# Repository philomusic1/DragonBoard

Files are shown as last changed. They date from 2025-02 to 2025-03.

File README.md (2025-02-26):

This is my keyboard inspired by the Corne Split Keyboard

It is a 58 Key Keyboard, with 2 Rotary encoders which have their switches wired into the Keyboard Switches matrix so it can be used as 60% keyboard
It is designed to be compatible with the Nice!Nano v2 and niceview display (the display can be swapped out for a oled one)
It is a reverisble PCB, so you only needs to send 1 gerber to your PCB manufacturer saving on costs and making it easier
The case is an acrylic case with a display protecter added
It is designed to be a wireless Keyboard with cherry mx hotswap switches with Per key RGB using SK6812 mini-e

Photos of the board follow Below:

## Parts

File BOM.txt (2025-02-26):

Bill of materials

10x 9mm M2 spacers/standoffs https://www.aliexpress.com/item/4000136343429.html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

4x 12mm M2 spacers/standoffs female threaded https://www.aliexpress.com/item/4000136343429.html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

28x 4mm M2 Screws https://mechboards.co.uk/products/m2-screws?variant=40295475740877

2x Wireless Pro Micro MCUs https://www.aliexpress.com/item/1005007738886550.html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

4x 12 4mm spring pin headers and sockets

58x Gateron G Pro 3.0 Silver https://www.mechmods.co.uk/products/gateron-g-pro-3-0-speed-silver-switches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

58x Cherry MX keyboard switch sockets https://mechboards.co.uk/products/kailh-hotswap-sockets

58x keycaps. https://www.aliexpress.com/item/1005008131935903.html?spm=a2g0o.cart.0.0.6f5338daPuBV3f&mp=1#nav-review

58x SK6812 Mini leds https://mechboards.co.uk/products/rgb-smd-leds?variant=40436774011085

58x 100nF Ceramic Capacitors https://www.digikey.co.uk/en/products/detail/samsung-electro-mechanics/CL05B104KP5VPNC/20498482

1x AO3401A Transistor https://www.digikey.co.uk/en/products/detail/alpha-omega-semiconductor-inc/AO3401A/1855773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

1x 2N7002 Transistor https://www.digikey.co.uk/en/products/detail/onsemi/2N7002/244345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

2x 0402 10k resistors https://www.digikey.co.uk/en/products/detail/samsung-electro-mechanics/RC1005F103CS/3903439

1x 0402 100 resistor https://www.digikey.co.uk/en/products/detail/yageo/RC0402JR-07100RL/726415

60x diodes 1N4148W SOD123 package https://www.digikey.co.uk/en/products/detail/diodes-incorporated/1N4148W-13-F/1933928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

2 buttons Momentary, tactile, through-hole, 2 pins: 3x6x4.3mm. https://www.digikey.co.uk/en/products/detail/c-k/PTS636-SM25F-SMTR-LFS/10071742

2 SPDT SMT slide switches https://www.digikey.co.uk/en/products/detail/nidec-copal-electronics/CUS-12TB/1124222

2 JST headers https://www.digikey.co.uk/en/products/detail/jst-sales-america-inc/S2B-PH-K-S/926626

4x LiPo Batteries 306080 https://www.aliexpress.com/item/1005006257821127.html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

2x OLED Displays https://www.aliexpress.com/item/1005007069127189.html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

2x ec11 encoder https://mechboards.co.uk/products/rotary-encoder

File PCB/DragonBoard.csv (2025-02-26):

Id | Designator | Footprint | Quantity | Designation | Supplier and ref
1 | SW_BATT+1,SW_BATT+2 | SW_SPDT_PCM12 | 2 | SW_SPST
2 | SW31 | RotaryEncoder_Alps_EC11E-Switch_Vertical_H20mm-keebio_modified | 1 | Rotary_Encoder_Switch
3 | TH7,TH4,TH6,TH3,TH5 | HOLE_M2_TH | 5 | HOLE
4 | U1 | ProMicro | 1 | ProMicro
5 | JP1,JP2,JP3,JP4,JP0,JP7,JP8,JP9,JP6,JP5 | Jumper_small | 10 | Jumper_NO_Small
6 | RSW1 | TACT_SWITCH_TVBP06 | 1 | SW_RST
7 | D1,D2,D3,D4,D5,D6,D13,D19,D25,D26,D7,D8,D9,D10,D11,D12,D27,D15,D16,D17,D18,D28,D29,D24,D20,D21,D22,D23,D14,D30 | crkbd-diode | 30 | D
8 | SW1,SW3,SW13,SW14,SW19,SW21,SW23,SW26,SW27,SW12,SW18,SW24,SW4,SW5,SW8,SW10,SW9,SW16,SW6,SW7,SW30,SW11,SW22,SW17,SW29,SW15,SW2,SW20,SW28 | SK6812MINI_and_cherry | 29 | SW_PUSH_LED
9 | TH1,TH2 | M2_HOLE_PCB | 2 | HOLE
10 | J3 | OLED_NICEVIEW_COMBO_HDR_5Pin | 1 | OLED
11 | JST_BATT2,JST_BATT1 | JST_PH_S2B-PH-K_1x02_P2.00mm_DoubleSided | 2 | Conn_01x02

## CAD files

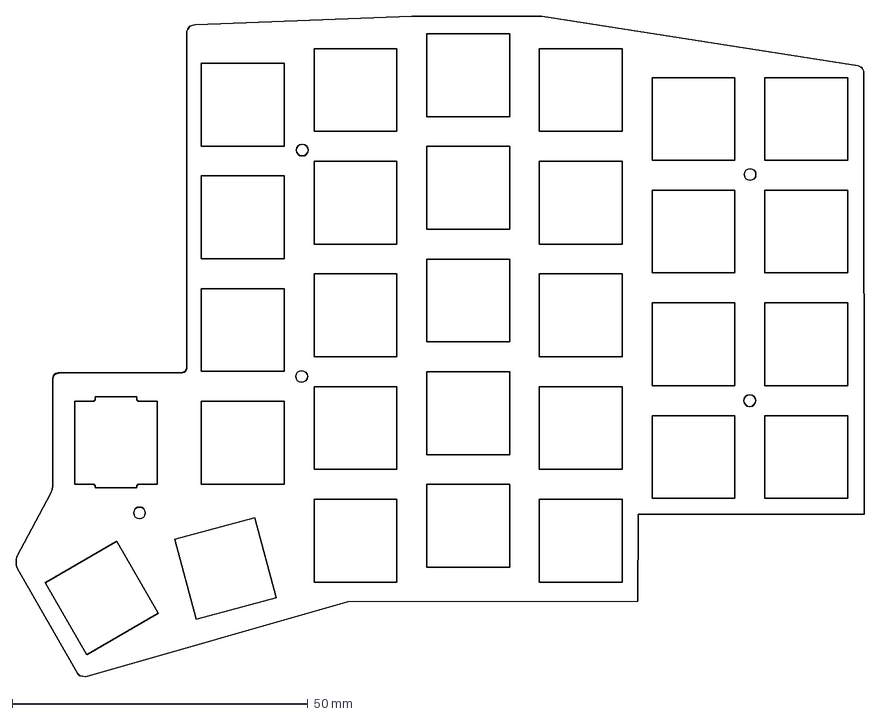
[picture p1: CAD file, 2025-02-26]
Case/Top Plate.dxf
143.4 x 111.7 mm

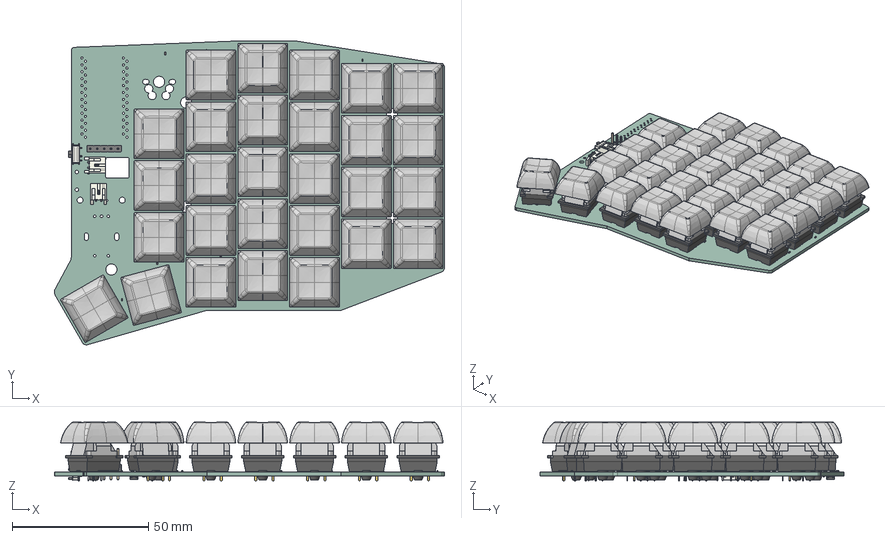
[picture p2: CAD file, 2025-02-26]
Case/DragonBoard.step
143.4 x 111.8 x 21.6 mm
PinHeader_1x05_P2.54mm_Vertical
C_0402_1005Metric x 29
Button x 28
Pins x 28
DSA_Keycap_CherryMX x 28
JST_PH_S2B-PH-K_1x02_P2.00mm_Horizontal x 2
SW_SPDT_PCM12 x 2
R_0402_1005Metric x 3
SOT-23 x 2
DragonBoard_PCB

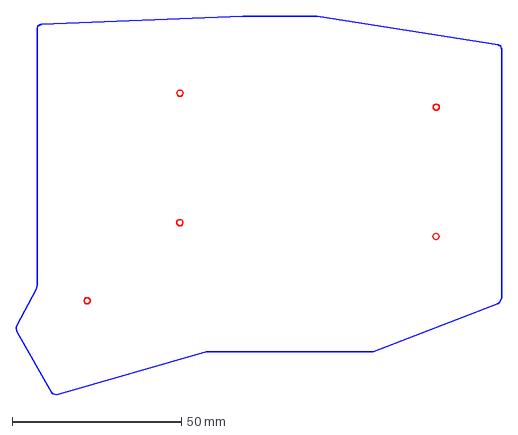
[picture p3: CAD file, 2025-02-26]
Case/Bottom Plate.dxf
143.5 x 111.9 mm

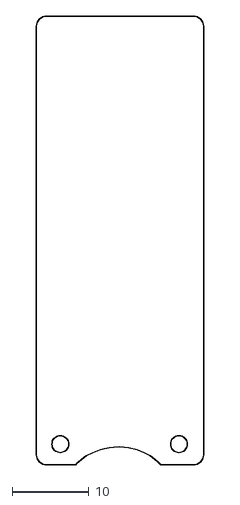
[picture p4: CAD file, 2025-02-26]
Case/OLED cover.dxf
21.8 x 58.6

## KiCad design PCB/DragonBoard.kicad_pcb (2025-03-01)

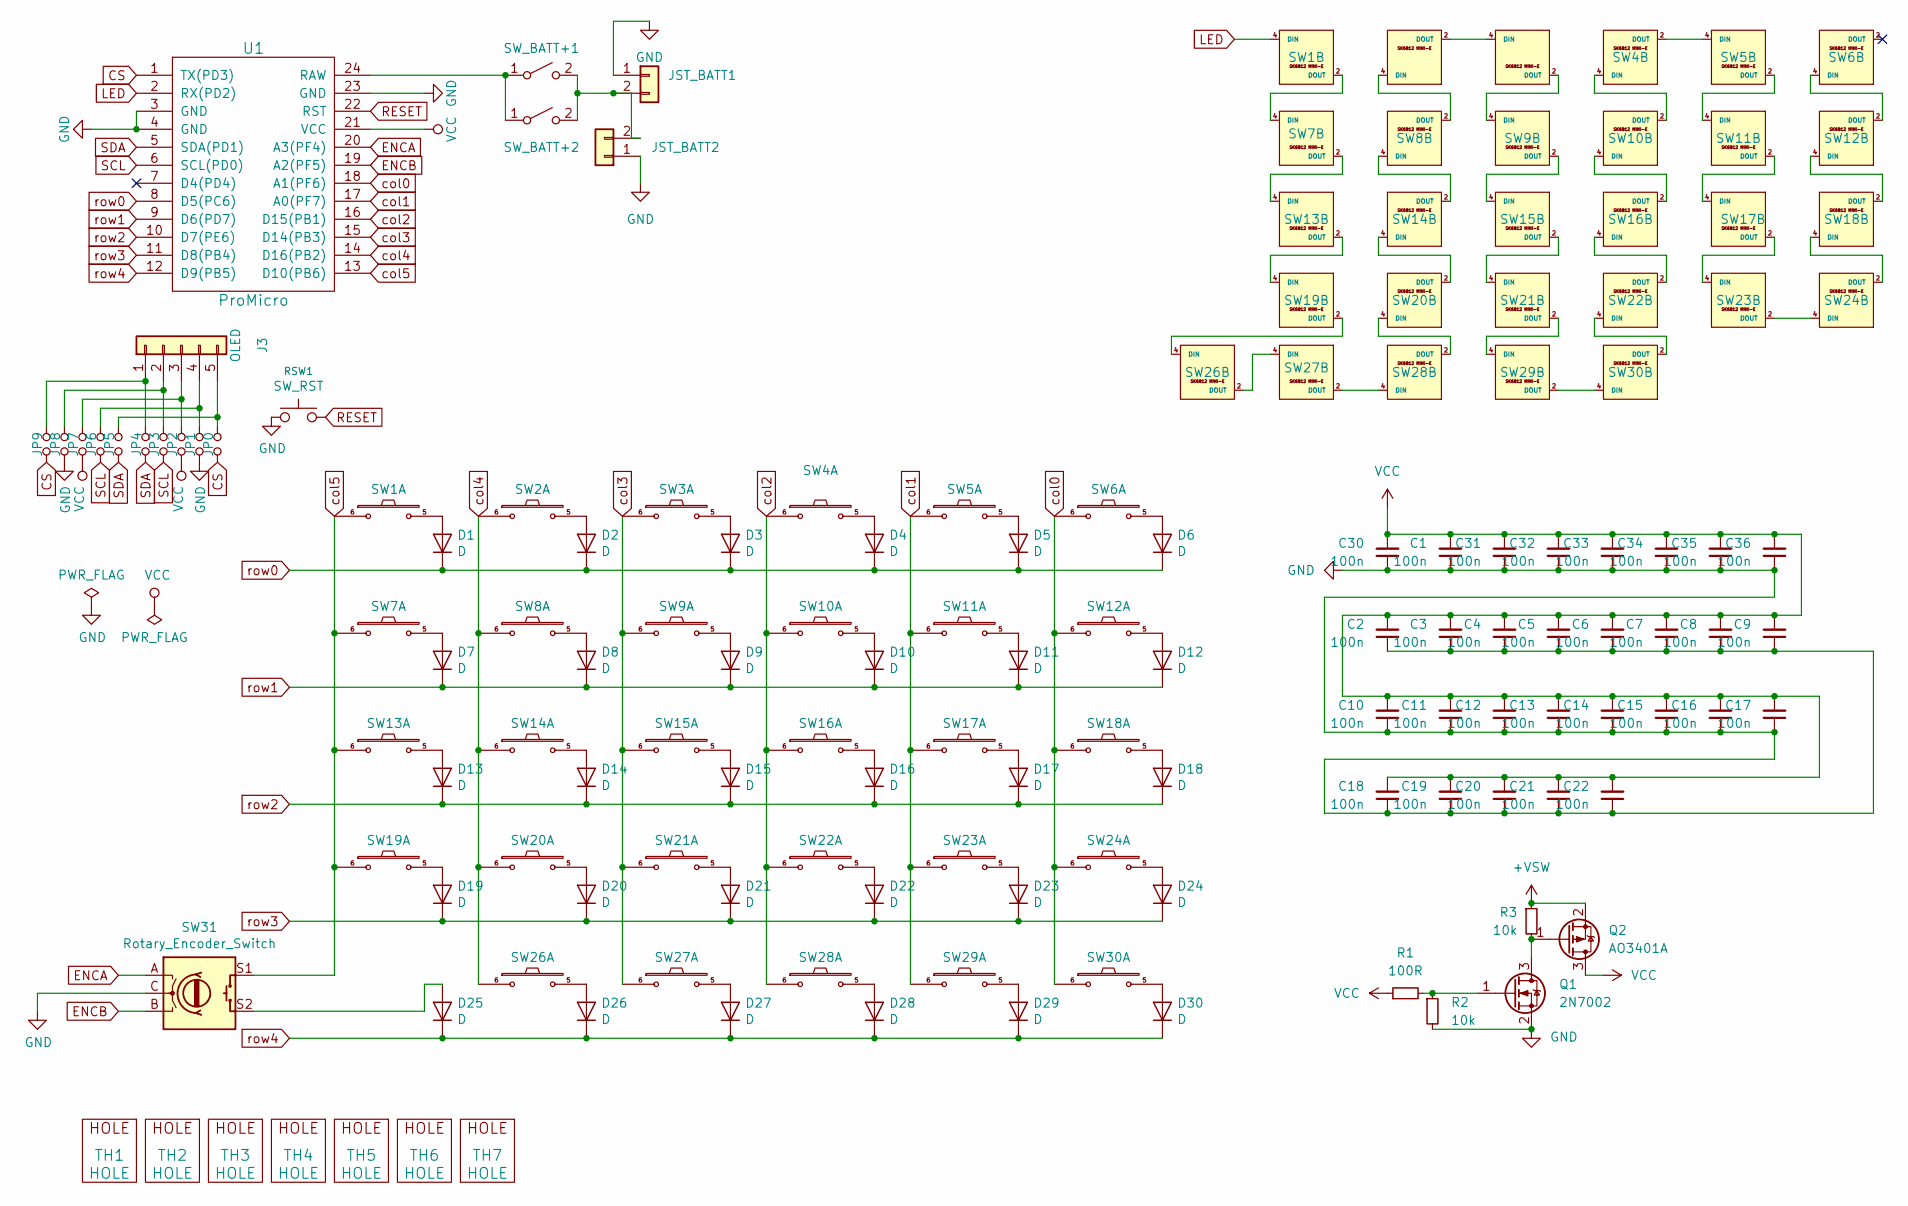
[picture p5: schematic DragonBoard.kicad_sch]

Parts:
C1, C2, C3, C4, C5, C6, C7, C8, C9, C10, C11, C12, C13, C14, C15, C16, C17, C18, C19, C20, C21, C22, C30, C31, C32, C33, C34, C35, C36: 100n; C_0402_1005Metric_Pad0.74x0.62mm_HandSolder
D1, D2, D3, D4, D5, D6, D7, D8, D9, D10, D11, D12, D13, D14, D15, D16, D17, D18, D19, D20, D21, D22, D23, D24, D25, D26, D27, D28, D29, D30: D; crkbd-diode
J3: OLED; OLED_NICEVIEW_COMBO_HDR_5Pin
JP0, JP1, JP2, JP3, JP4, JP5, JP6, JP7, JP8, JP9: Jumper_NO_Small; Jumper_small
JST_BATT1, JST_BATT2: Conn_01x02; JST_PH_S2B-PH-K_1x02_P2.00mm_DoubleSided
Q1: 2N7002; SOT-23
Q2: AO3401A; SOT-23
R1: 100R; R_0402_1005Metric_Pad0.72x0.64mm_HandSolder
R2, R3: 10k; R_0402_1005Metric_Pad0.72x0.64mm_HandSolder
RSW1: SW_RST; TACT_SWITCH_TVBP06
SW1, SW2, SW3, SW4, SW5, SW6, SW7, SW8, SW9, SW10, SW11, SW12, SW13, SW14, SW15, SW16, SW17, SW18, SW19, SW20, SW21, SW22, SW23, SW24, SW26, SW27, SW28, SW29, SW30: SW_PUSH_LED; SK6812MINI_and_cherry
SW31: Rotary_Encoder_Switch; RotaryEncoder_Alps_EC11E-Switch_Vertical_H20mm-keebio_modif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
SW_BATT+1, SW_BATT+2: SW_SPST; SW_SPDT_PCM12
TH1, TH2: HOLE; M2_HOLE_PCB
TH3, TH4, TH5, TH6, TH7: HOLE; HOLE_M2_TH
U1: ProMicro

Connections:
+VSW: Q2.2 (S), R3.1
CS: JP0.2, JP9.2, U1.1 (TX(PD3))
ENCA: SW31.A, U1.20 (A3(PF4))
ENCB: SW31.B, U1.19 (A2(PF5))
GND: C1.1, C2.1, C3.1, C4.1, C5.1, C6.1, C7.1, C8.1, C9.1, C10.1, C11.1, C12.1, C13.1, C14.1, C15.1, C16.1, C17.1, C18.1, C19.1, C20.1, C21.1, C22.1, C30.1, C31.1, C32.1, C33.1, C34.1, C35.1, C36.1, JP1.2, JP8.2, JST_BATT1.1, JST_BATT2.1, Q1.2 (S), R2.2, RSW1.1, SW1.3 (GND), SW2.3 (GND), SW3.3 (GND), SW4.3 (GND), SW5.3 (GND), SW6.3 (GND), SW7.3 (GND), SW8.3 (GND), SW9.3 (GND), SW10.3 (GND), SW11.3 (GND), SW12.3 (GND), SW13.3 (GND), SW14.3 (GND), SW15.3 (GND), SW16.3 (GND), SW17.3 (GND), SW18.3 (GND), SW19.3 (GND), SW20.3 (GND), SW21.3 (GND), SW22.3 (GND), SW23.3 (GND), SW24.3 (GND), SW26.3 (GND), SW27.3 (GND), SW28.3 (GND), SW29.3 (GND), SW30.3 (GND), SW31.C, U1.3 (GND), U1.4 (GND), U1.23 (GND)
LED: SW1.4 (DIN), U1.2 (RX(PD2))
unnamed: D1.2 (A), SW1.5
unnamed: D2.2 (A), SW2.5
unnamed: D3.2 (A), SW3.5
unnamed: D4.2 (A), SW4.5
unnamed: D5.2 (A), SW5.5
unnamed: D6.2 (A), SW6.5
unnamed: D7.2 (A), SW7.5
unnamed: D8.2 (A), SW8.5
unnamed: D9.2 (A), SW9.5
unnamed: D10.2 (A), SW10.5
unnamed: D11.2 (A), SW11.5
unnamed: D12.2 (A), SW12.5
unnamed: D13.2 (A), SW13.5
unnamed: D14.2 (A), SW14.5
unnamed: D15.2 (A), SW15.5
unnamed: D16.2 (A), SW16.5
unnamed: D17.2 (A), SW17.5
unnamed: D18.2 (A), SW18.5
unnamed: D19.2 (A), SW19.5
unnamed: D20.2 (A), SW20.5
unnamed: D21.2 (A), SW21.5
unnamed: D22.2 (A), SW22.5
unnamed: D23.2 (A), SW23.5
unnamed: D24.2 (A), SW24.5
unnamed: D25.2 (A), SW31.S2
unnamed: D26.2 (A), SW26.5
unnamed: D27.2 (A), SW27.5
unnamed: D28.2 (A), SW28.5
unnamed: D29.2 (A), SW29.5
unnamed: D30.2 (A), SW30.5
unnamed: J3.1, JP4.1, JP9.1
unnamed: J3.2, JP3.1, JP8.1
unnamed: J3.3, JP2.1, JP7.1
unnamed: J3.4, JP1.1, JP6.1
unnamed: J3.5, JP0.1, JP5.1
unnamed: JST_BATT1.2, JST_BATT2.2, SW_BATT+1.2 (B), SW_BATT+2.2 (B)
unnamed: Q1.3 (D), Q2.1 (G), R3.2
unnamed: Q1.1 (G), R1.2, R2.1
unnamed: SW1.2 (DOUT), SW7.4 (DIN)
unnamed: SW2.4 (DIN), SW8.2 (DOUT)
unnamed: SW2.2 (DOUT), SW3.4 (DIN)
unnamed: SW3.2 (DOUT), SW9.4 (DIN)
unnamed: SW4.2 (DOUT), SW5.4 (DIN)
unnamed: SW10.4 (DIN), SW16.2 (DOUT)
unnamed: SW4.4 (DIN), SW10.2 (DOUT)
unnamed: SW5.2 (DOUT), SW11.4 (DIN)
unnamed: SW11.2 (DOUT), SW17.4 (DIN)
unnamed: SW12.4 (DIN), SW18.2 (DOUT)
unnamed: SW6.4 (DIN), SW12.2 (DOUT)
unnamed: SW7.2 (DOUT), SW13.4 (DIN)
unnamed: SW13.2 (DOUT), SW19.4 (DIN)
unnamed: SW14.4 (DIN), SW20.2 (DOUT)
unnamed: SW8.4 (DIN), SW14.2 (DOUT)
unnamed: SW9.2 (DOUT), SW15.4 (DIN)
unnamed: SW15.2 (DOUT), SW21.4 (DIN)
unnamed: SW16.4 (DIN), SW22.2 (DOUT)
unnamed: SW17.2 (DOUT), SW23.4 (DIN)
unnamed: SW18.4 (DIN), SW24.2 (DOUT)
unnamed: SW19.2 (DOUT), SW26.4 (DIN)
unnamed: SW20.4 (DIN), SW28.2 (DOUT)
unnamed: SW21.2 (DOUT), SW29.4 (DIN)
unnamed: SW22.4 (DIN), SW30.2 (DOUT)
unnamed: SW23.2 (DOUT), SW24.4 (DIN)
unnamed: SW26.2 (DOUT), SW27.4 (DIN)
unnamed: SW27.2 (DOUT), SW28.4 (DIN)
unnamed: SW29.2 (DOUT), SW30.4 (DIN)
unnamed: SW_BATT+1.1 (A), SW_BATT+2.1 (A), U1.24 (RAW)
RESET: RSW1.2, U1.22 (RST)
SCL: JP3.2, JP6.2, U1.6 (SCL(PD0))
SDA: JP4.2, JP5.2, U1.5 (SDA(PD1))
VCC: C1.2, C2.2, C3.2, C4.2, C5.2, C6.2, C7.2, C8.2, C9.2, C10.2, C11.2, C12.2, C13.2, C14.2, C15.2, C16.2, C17.2, C18.2, C19.2, C20.2, C21.2, C22.2, C30.2, C31.2, C32.2, C33.2, C34.2, C35.2, C36.2, JP2.2, JP7.2, Q2.3 (D), R1.1, SW1.1 (VCC), SW2.1 (VCC), SW3.1 (VCC), SW4.1 (VCC), SW5.1 (VCC), SW6.1 (VCC), SW7.1 (VCC), SW8.1 (VCC), SW9.1 (VCC), SW10.1 (VCC), SW11.1 (VCC), SW12.1 (VCC), SW13.1 (VCC), SW14.1 (VCC), SW15.1 (VCC), SW16.1 (VCC), SW17.1 (VCC), SW18.1 (VCC), SW19.1 (VCC), SW20.1 (VCC), SW21.1 (VCC), SW22.1 (VCC), SW23.1 (VCC), SW24.1 (VCC), SW26.1 (VCC), SW27.1 (VCC), SW28.1 (VCC), SW29.1 (VCC), SW30.1 (VCC), U1.21 (VCC)
col0: SW6.6, SW12.6, SW18.6, SW24.6, SW30.6, U1.18 (A1(PF6))
col1: SW5.6, SW11.6, SW17.6, SW23.6, SW29.6, U1.17 (A0(PF7))
col2: SW4.6, SW10.6, SW16.6, SW22.6, SW28.6, U1.16 (D15(PB1))
col3: SW3.6, SW9.6, SW15.6, SW21.6, SW27.6, U1.15 (D14(PB3))
col4: SW2.6, SW8.6, SW14.6, SW20.6, SW26.6, U1.14 (D16(PB2))
col5: SW1.6, SW7.6, SW13.6, SW19.6, SW31.S1, U1.13 (D10(PB6))
row0: D1.1 (K), D2.1 (K), D3.1 (K), D4.1 (K), D5.1 (K), D6.1 (K), U1.8 (D5(PC6))
row1: D7.1 (K), D8.1 (K), D9.1 (K), D10.1 (K), D11.1 (K), D12.1 (K), U1.9 (D6(PD7))
row2: D13.1 (K), D14.1 (K), D15.1 (K), D16.1 (K), D17.1 (K), D18.1 (K), U1.10 (D7(PE6))
row3: D19.1 (K), D20.1 (K), D21.1 (K), D22.1 (K), D23.1 (K), D24.1 (K), U1.11 (D8(PB4))
row4: D25.1 (K), D26.1 (K), D27.1 (K), D28.1 (K), D29.1 (K), D30.1 (K), U1.12 (D9(PB5))

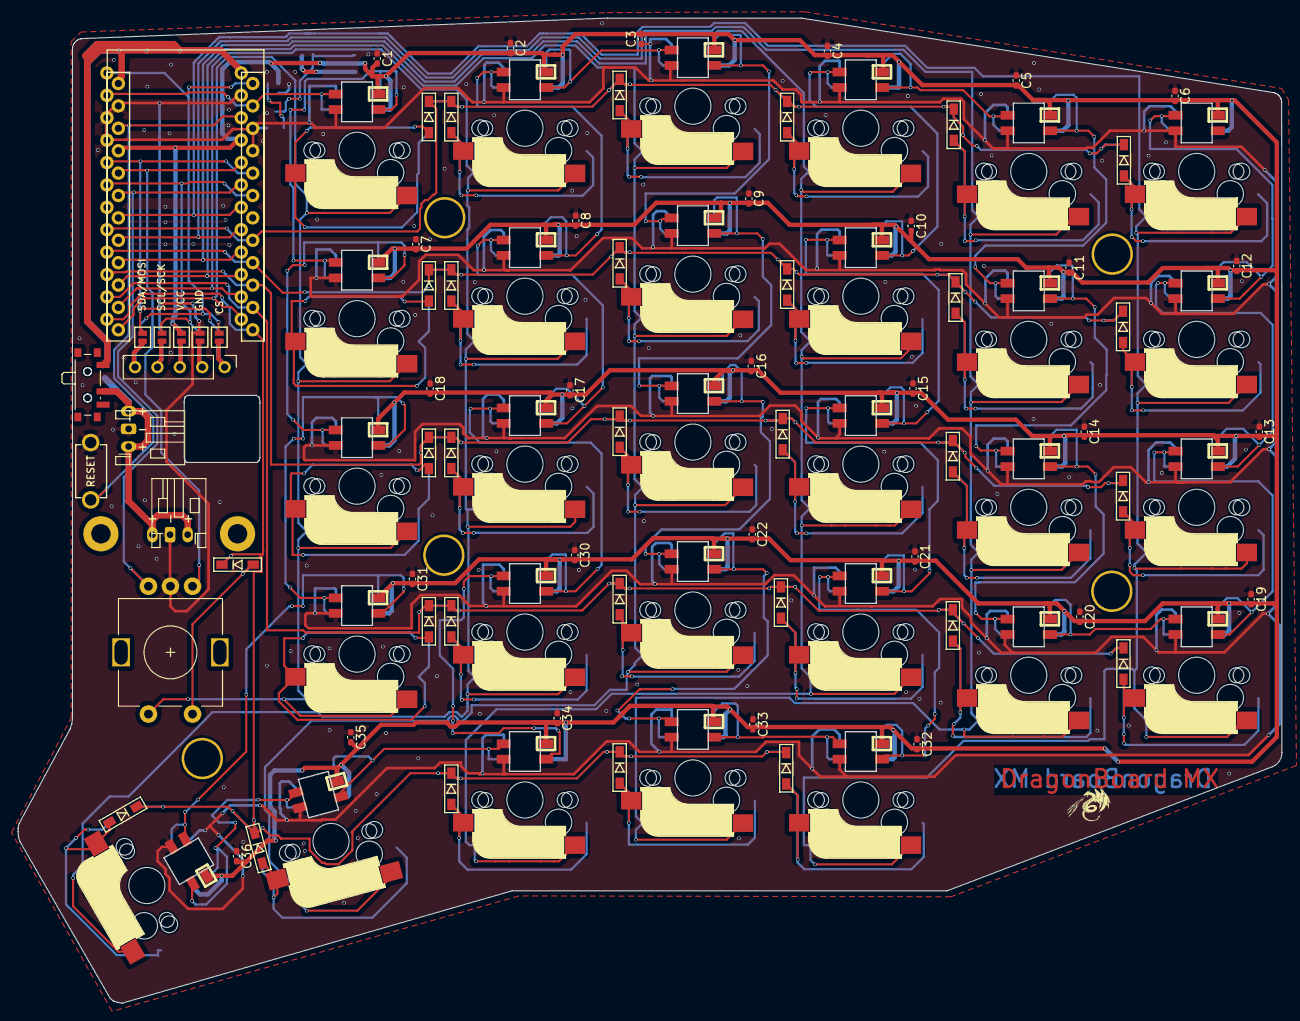
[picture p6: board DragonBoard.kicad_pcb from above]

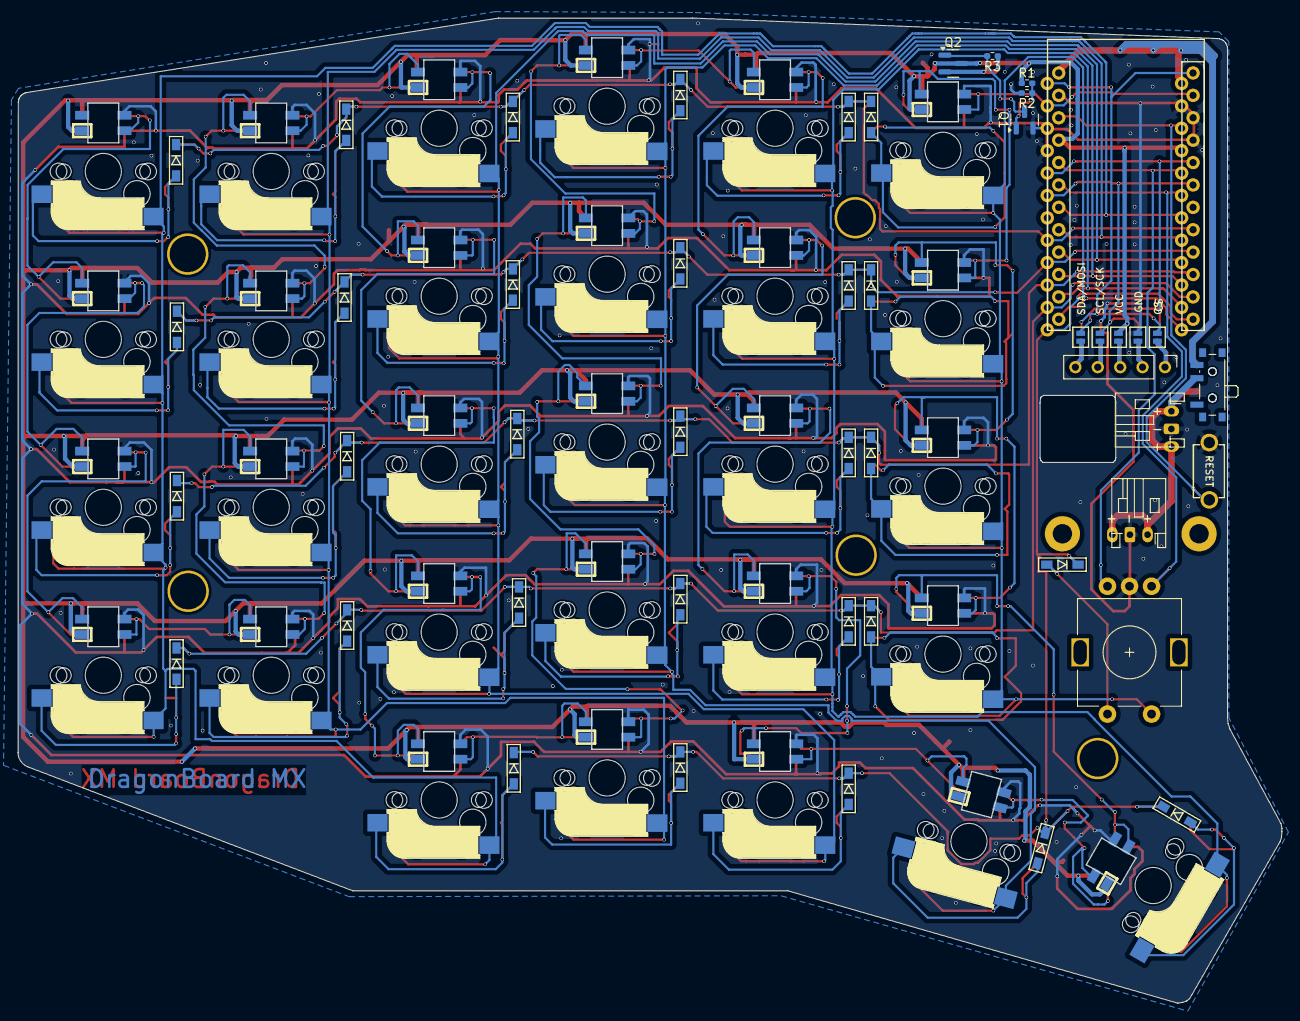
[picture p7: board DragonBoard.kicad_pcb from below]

Board: 2 copper layers, 143.4 x 111.8 mm, 118 parts (11 on the bottom side), 88 nets.

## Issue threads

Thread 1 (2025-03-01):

DFM Check

YeetTheAnson, 2025-03-01:
Nice split KB, but I believe there's some issues with the PCB

1. Multiple traces are way too close to the edges
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

2. Multiple vias are too close together
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

Summary
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

You can view the rest of the errors on [JLCDFM](https://jlcdfm.com/viewer?pcbUploadFileId=418748778591944706)

philomusic1, 2025-03-01:
All solved now

YeetTheAnson, 2025-03-01:
nice, nice.
I'm really impressed with your reversable PCB lol

Closed 2025-03-01.

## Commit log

2025-02-26 initial repo
    [Bottom Plate.dxf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]
2025-02-26 update BoM
2025-03-01 update pcb and gerber to latest
    [DragonBoard-B_Courtyard.gbr, DragonBoard-B_Cu.gbl, DragonBoard-B_Mask.gbs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]
2025-03-01 update pricing of BoM
2025-03-01 add missing sockets
2025-03-01 clarify socket kit
2025-03-01 fix the JLCDFM errors
    [DragonBoard-B_Courtyard.gbr, DragonBoard-B_Cu.gbl, DragonBoard-B_Mask.gbs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]
2025-03-01 fix further JLCDFM errors
    [DragonBoard-B_Courtyard.gbr, DragonBoard-B_Cu.gbl, DragonBoard-B_Mask.gbs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]
2025-03-01 fix remaining DFM checks
    [DragonBoard-B_Courtyard.gbr, DragonBoard-B_Cu.gbl, DragonBoard-B_Mask.gbs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]
